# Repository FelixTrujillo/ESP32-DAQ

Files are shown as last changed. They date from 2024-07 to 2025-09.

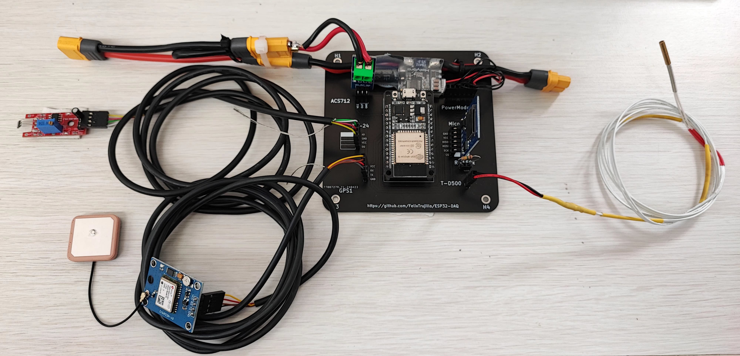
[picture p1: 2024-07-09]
Documentation/Images/DAQ_assembled.jpeg

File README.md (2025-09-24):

# ESP32-DAQ
This repository contains the code and design of a data acquisition device for the battery system of an electric vehicle. Developed with the ESP-WROOM-32, this device records current, voltage, speed and GPS data accurately and efficiently.

Bill of materials: ESP-WROOM-32, Current sensor ACS-712, Power module Holybro PM02, Hall effect sensor KY-024, NEO-6M GPS module, Micro SD storage module, T-D500 Temperature Sensor

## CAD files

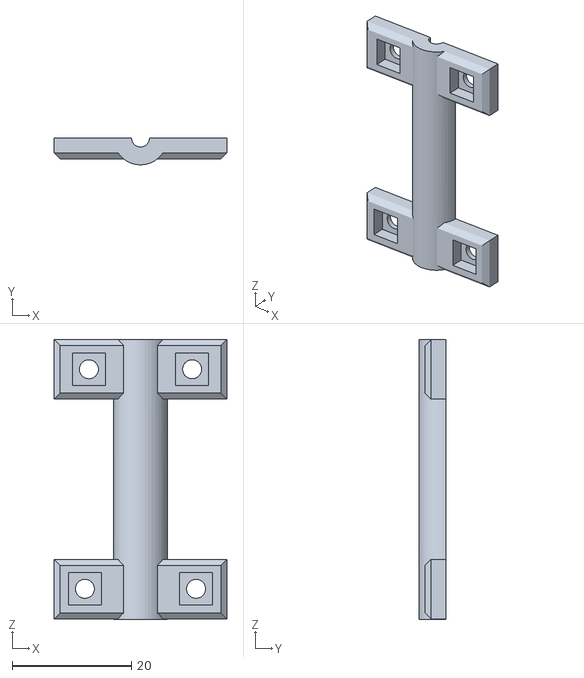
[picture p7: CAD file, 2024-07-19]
DAQ-STEP/BicinetaIman_Soporte_backward_stl.stl
29.0 x 4.50 x 47.0

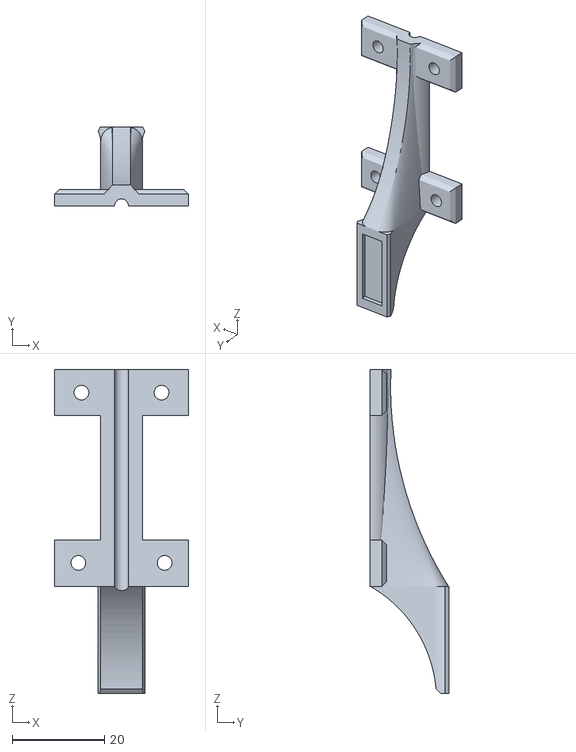
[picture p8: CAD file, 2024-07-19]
DAQ-STEP/Bicineta_Iman_Soporte_Forward_stl.stl
29.0 x 17.0 x 70.1

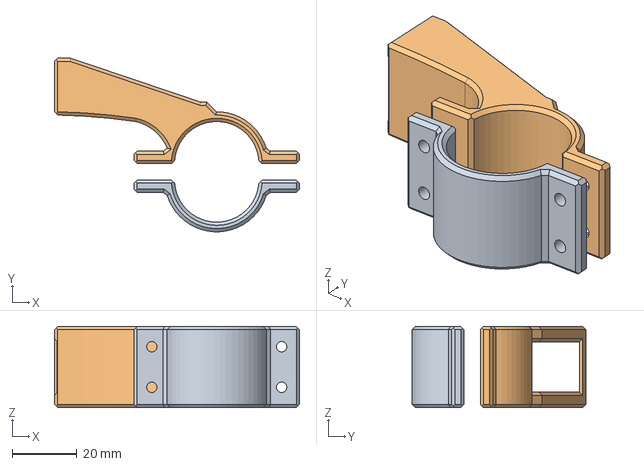
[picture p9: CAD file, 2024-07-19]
DAQ-STEP/Bicineta-stand-ky-024.step
75.5 x 53.5 x 25.0 mm

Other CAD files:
DAQ-STEP/Bicineta_Iman_Soporte_Forward.step
DAQ-STEP/BicinetaIman_Soporte_backward.step

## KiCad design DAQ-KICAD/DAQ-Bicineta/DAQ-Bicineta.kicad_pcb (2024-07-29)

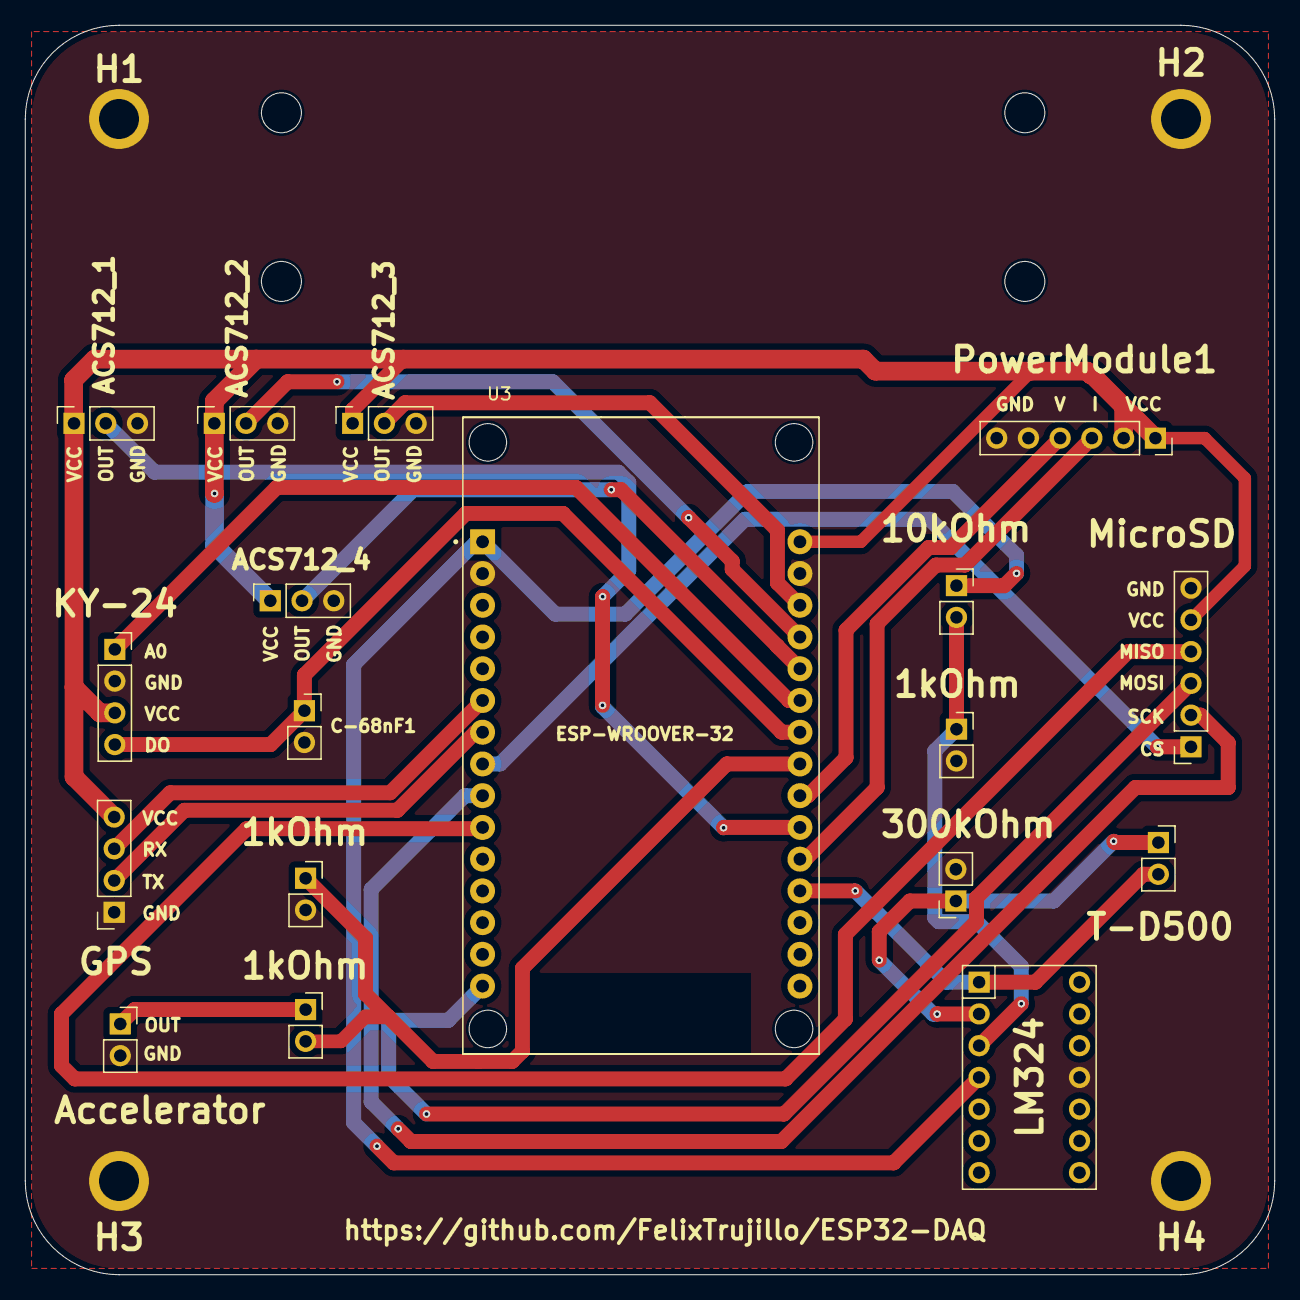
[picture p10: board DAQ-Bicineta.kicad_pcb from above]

Board: 2 copper layers, 100.0 x 100.0 mm, 22 parts (0 on the bottom side), 22 nets.

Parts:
1kOhm, 1kOhm#2, 1kOhm#3, 10kOhm, 300kOhm: R; PinSocket_1x02_P2.54mm_Vertical
ACS712_1, ACS712_2, ACS712_3, ACS712_4: Conn_01x03; PinSocket_1x03_P2.54mm_Vertical
Accelerator: Conn_01x02; PinSocket_1x02_P2.54mm_Vertical
C-68nF1: C_Small; PinSocket_1x02_P2.54mm_Vertical
GPS: Conn_01x04; PinSocket_1x04_P2.54mm_Vertical
H1, H2, H3, H4: MountingHole_2.2mm_M2_ISO7380_Pad
KY-24: Conn_01x04; PinSocket_1x04_P2.54mm_Vertical
LM324: Conn_02x07_Odd_Even; LM324
MicroSD: Conn_01x06; PinSocket_1x06_P2.54mm_Vertical
PowerModule1: Conn_01x06; PinSocket_1x06_P2.54mm_Vertical
T-D500: Conn_01x02; PinSocket_1x02_P2.54mm_Vertical
U3: ESP32-DEVKIT-V1; MODULE_ESP32_DEVKIT_V1

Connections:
ACCELERATOR_GND: 1kOhm#2.2, 1kOhm#3.2, 300kOhm.2, ACS712_1.3, ACS712_2.3, ACS712_3.3, ACS712_4.3, Accelerator.2, C-68nF1.2, GPS.1, H1.1, H2.2, H3.3, H4.4, KY-24.2, LM324.8, MicroSD.6, PowerModule1.5, PowerModule1.6, U3.2 (GND), U3.29 (GND)
ACCELERATOR_Vout: 1kOhm.2, 1kOhm#3.1, U3.23 (D25)
CS_OUT_1: ACS712_1.2, U3.21 (D32)
CS_OUT_2: ACS712_2.2, U3.27 (D12)
CS_OUT_3: ACS712_3.2, U3.28 (D13)
CS_OUT_4: ACS712_4.2, U3.26 (D14)
CS_VCC: ACS712_1.1, ACS712_2.1, ACS712_3.1, ACS712_4.1, GPS.4, KY-24.3, MicroSD.5, PowerModule1.1, PowerModule1.2, U3.30 (VIN)
GPS_RX: GPS.3, U3.6 (RX2)
GPS_TX: GPS.2, U3.7 (TX2)
KY_A0: KY-24.1, U3.25 (D27)
KY_DO: C-68nF1.1, KY-24.4, U3.24 (D26)
MSD_CS: MicroSD.1, U3.8 (D5)
MSD_MISO: MicroSD.4, U3.10 (D19)
MSD_MOSI: MicroSD.3, U3.15 (D23)
MSD_SCK: MicroSD.2, U3.9 (D18)
unnamed: 1kOhm.1, Accelerator.1
unnamed: 300kOhm.1, LM324.3, T-D500.1
unnamed: 1kOhm#2.1, 10kOhm.2, LM324.5
PM_I: PowerModule1.3, U3.20 (D35)
PM_V: PowerModule1.4, U3.22 (D33)
T-D500_OUT: LM324.1, T-D500.2, U3.19 (D34)
T-D500_VCC: 10kOhm.1, LM324.7, U3.1 (3V3)

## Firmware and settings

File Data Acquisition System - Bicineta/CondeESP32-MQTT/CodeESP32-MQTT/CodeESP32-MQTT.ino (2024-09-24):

#include "SD.h"
#include <Arduino.h>
#include <ESP32Servo.h>
#include <TinyGPS++.h>
#include <Wire.h>
#include <HardwareSerial.h>
#include <math.h>

#include <WiFi.h>
#include <PubSubClient.h>
#include <WiFiClientSecure.h>

#define RXD2 16 // Pin RX GPS
#define TXD2 17 // Pin TX GPS
#define GPS_BAUD 9600  // Velocidad de baudios del módulo GPS
#define NMEA 0

// =============================================================

double pinA = 26; // Pin sensor efecto hall
double pinB = 27; // Pin sensor efecto hall analogo (No en uso)

double pinV = 33;  //Pin medir tension PM
double pinI = 32; // Pin medir corriente ACS712
double pin_I = 35; // Pin medir corriente PM (No en uso)
double pinT = 34; // Pin medir temperatura T-D500

int pinCS = 5; // Pin modulo memoria

int pinACC = 39; // Pin Acelerador

// =============================================================


//---- WiFi settings
const char* ssid = "UTP";
const char* password = "tecnologica";
//---- MQTT Broker settings
const char* mqtt_server = "02c9970343eb456bac87e5836a2905c3.s1.eu.hivemq.cloud"; // replace with your broker url
const char* mqtt_username = "GCA_DAQ";
const char* mqtt_password = "#Control2005";
const int mqtt_port =8883;

WiFiClientSecure espClient;
PubSubClient client(espClient);
unsigned long lastMsg = 0;

#define MSG_BUFFER_SIZE (50)
char msg[MSG_BUFFER_SIZE];

const char* sensor1_topic= "voltage";
const char* sensor2_topic= "current";
const char* sensor3_topic= "speed";
const char* sensor4_topic= "acceleration";
const char* sensor5_topic= "temperature";
const char* sensor6_topic= "altitud";


static const char *root_ca PROGMEM = R"EOF(
-----BEGIN CERTIFICATE-----
MIIFazCCA1OgAwIBAgIRAIIQz7DSQONZRGPgu2OCiwAwDQYJKoZIhvcNAQELBQAw
TzELMAkGA1UEBhMCVVMxKTAnBgNVBAoTIEludGVybmV0IFNlY3VyaXR5IFJlc2Vh
cmNoIEdyb3VwMRUwEwYDVQQDEwxJU1JHIFJvb3QgWDEwHhcNMTUwNjA0MTEwNDM4
WhcNMzUwNjA0MTEwNDM4WjBPMQswCQYDVQQGEwJVUzEpMCcGA1UEChMgSW50ZXJu
ZXQgU2VjdXJpdHkgUmVzZWFyY2ggR3JvdXAxFTATBgNVBAMTDElTUkcgUm9vdCBY
MTCCAiIwDQYJKoZIhvcNAQEBBQADggIPADCCAgoCggIBAK3oJHP0FDfzm54rVygc
h77ct984kIxuPOZXoHj3dcKi/vVqbvYATyjb3miGbESTtrFj/RQSa78f0uoxmyF+
0TM8ukj13Xnfs7j/EvEhmkvBioZxaUpmZmyPfjxwv60pIgbz5MDmgK7iS4+3mX6U
A5/TR5d8mUgjU+g4rk8Kb4Mu0UlXjIB0ttov0DiNewNwIRt18jA8+o+u3dpjq+sW
T8KOEUt+zwvo/7V3LvSye0rgTBIlDHCNAymg4VMk7BPZ7hm/ELNKjD+Jo2FR3qyH
B5T0Y3HsLuJvW5iB4YlcNHlsdu87kGJ55tukmi8mxdAQ4Q7e2RCOFvu396j3x+UC
B5iPNgiV5+I3lg02dZ77DnKxHZu8A/lJBdiB3QW0KtZB6awBdpUKD9jf1b0SHzUv
KBds0pjBqAlkd25HN7rOrFleaJ1/ctaJxQZBKT5ZPt0m9STJEadao0xAH0ahmbWn
OlFuhjuefXKnEgV4We0+UXgVCwOPjdAvBbI+e0ocS3MFEvzG6uBQE3xDk3SzynTn
jh8BCNAw1FtxNrQHusEwMFxIt4I7mKZ9YIqioymCzLq9gwQbooMDQaHWBfEbwrbw
qHyGO0aoSCqI3Haadr8faqU9GY/rOPNk3sgrDQoo//fb4hVC1CLQJ13hef4Y53CI
rU7m2Ys6xt0nUW7/vGT1M0NPAgMBAAGjQjBAMA4GA1UdDwEB/wQEAwIBBjAPBgNV
HRMBAf8EBTADAQH/MB0GA1UdDgQWBBR5tFnme7bl5AFzgAiIyBpY9umbbjANBgkq
hkiG9w0BAQsFAAOCAgEAVR9YqbyyqFDQDLHYGmkgJykIrGF1XIpu+ILlaS/V9lZL
ubhzEFnTIZd+50xx+7LSYK05qAvqFyFWhfFQDlnrzuBZ6brJFe+GnY+EgPbk6ZGQ
3BebYhtF8GaV0nxvwuo77x/Py9auJ/GpsMiu/X1+mvoiBOv/2X/qkSsisRcOj/KK
NFtY2PwByVS5uCbMiogziUwthDyC3+6WVwW6LLv3xLfHTjuCvjHIInNzktHCgKQ5
ORAzI4JMPJ+GslWYHb4phowim57iaztXOoJwTdwJx4nLCgdNbOhdjsnvzqvHu7Ur
TkXWStAmzOVyyghqpZXjFaH3pO3JLF+l+/+sKAIuvtd7u+Nxe5AW0wdeRlN8NwdC
jNPElpzVmbUq4JUagEiuTDkHzsxHpFKVK7q4+63SM1N95R1NbdWhscdCb+ZAJzVc
oyi3B43njTOQ5yOf+1CceWxG1bQVs5ZufpsMljq4Ui0/1lvh+wjChP4kqKOJ2qxq
4RgqsahDYVvTH9w7jXbyLeiNdd8XM2w9U/t7y0Ff/9yi0GE44Za4rF2LN9d11TPA
mRGunUHBcnWEvgJBQl9nJEiU0Zsnvgc/ubhPgXRR4Xq37Z0j4r7g1SgEEzwxA57d
emyPxgcYxn/eR44/KJ4EBs+lVDR3veyJm+kXQ99b21/+jh5Xos1AnX5iItreGCc=
-----END CERTIFICATE-----
)EOF";



// Inicializacion variables de corriente, tension, temperatura y aceleracion
double corriente = 0;
double temperatura = 0;
double voltaje = 0;
double accelerator = 0;

// Inicializacion vaiables del GPS
double latGPS;
double longGPS;
double velGPS;
double numSat;
double altGPS;
int hourGPS;
int minGPS;
int yearGPS;

// Parametros sensor de temperatura
double a = -0.015769;
double b = 0.0032072;
double c = -0.00018051;
double d = 3.3808e-06;

// Inicializacion variables sensor de velocidad (HY-024)
volatile int PPSCounter = 0; // Contador de pulsos
unsigned int pulsos = 0;     // Cantidad de pulsos en 1 segundo 
unsigned Time = 0;           // Inicialización variable de tiempo
float RPM = 0;        // Inicializacion variable de velocidad actual
unsigned int RPM_ANT = 0;    // Inicializacion variable de velocidad anterior
int PPR = 2;                // Numero de pulsos que detecta el sensor por vuelta
double debounceDelay = 120;
double debounceTime = 0;
double lastDebounceTime = 0;

// Parametros sensor de corriente ACS712
double mVperAmp = 0.1;       // Sensibilidad sensor de corriente ACS712

// Numero de muestras para la medicion de datos
int muestras = 1000;

TinyGPSPlus gps;
HardwareSerial gpsSerial(2);

File archivo;
String datos;

void IRAM_ATTR magnetDetection();
int getRPM();
double getCurrent(int numMuestras);
double getVoltage(int numMuestras1);
double getTemp(int numMuestras1);
double getSignalAcceleration(int numMuestras1);

void setup() {

  Serial.begin(115200);

  pinMode(pinCS, OUTPUT);
  pinMode(pinV, INPUT);
  pinMode(pinI, INPUT);
  pinMode(pinACC, INPUT);
  pinMode(pinA, INPUT_PULLUP);

  Serial.print("\nConnecting to ");
  Serial.println(ssid);
  WiFi.mode(WIFI_STA);
  WiFi.begin(ssid, password);
  while (WiFi.status() != WL_CONNECTED) {
  delay(500);
  Serial.print(".");
  }
  randomSeed(micros());
  Serial.println("\nWiFi connected\nIP address: ");
  Serial.println(WiFi.localIP());

  while (!Serial) delay(1);

  espClient.setCACert(root_ca);
  client.setServer(mqtt_server, mqtt_port);
  client.setCallback(callback);

  gpsSerial.begin(GPS_BAUD, SERIAL_8N1, RXD2, TXD2);

  attachInterrupt(digitalPinToInterrupt(pinA), magnetDetection, HIGH);

  Time = millis();

  

  if (!SD.begin(pinCS)) {
    Serial.println("ERROR:\n Puerto CS no inicializado.");
    ESP.restart();
  }
  Serial.println("Modulo CS inicializado.");

  archivo = SD.open("/registro.CSV", FILE_WRITE);
  if (!archivo) {
    Serial.println("ERROR:\n No se ha podido crear el archivo.");
    return;
  }

  archivo.println("Velocidad [RPM],Aceleracion [V_Acc], Voltaje[V],Corriente[A],Temperatura[°C],Latitud,Longitud,Velocidad[GPS: km/h],Satelites, Altitud, Hora, Minutos, Year");
  archivo.close();
}

void loop() {

    if (!client.connected()) reconnect();
  client.loop();


  // Apertura del archivo "Registro"
  archivo = SD.open("/registro.CSV", FILE_APPEND);

  // Lectura de velocidad con el encoder
  RPM = getRPM();
  accelerator = getSignalAcceleration(muestras); 
  // Lectura de temperatura
  temperatura = getTemp(muestras);

  // lectura de datos de tension y corriente
  voltaje = getVoltage(muestras);

  if (voltaje == 0 || corriente < 0) {
    corriente = 0;
  }
  else {
    corriente = getCurrent(muestras);
  }



  while (gpsSerial.available() > 0) {
    if (gps.encode(gpsSerial.read())) {
      if (gps.location.isUpdated()) {
        // Si se ha recibido una nueva actualización de ubicación, muestra la información
        latGPS = gps.location.lat();
        longGPS = gps.location.lng();
        velGPS = gps.speed.kmph();
        numSat = gps.satellites.value();
        altGPS = gps.altitude.meters();
        hourGPS = gps.time.hour();
        minGPS = gps.time.minute();
        yearGPS = gps.date.year();

        
      };
    };
  };
  // Creacion String datos para la generacion del formato .CSV
  if (archivo) {
          datos = String(String(RPM) +","+ String(accelerator) + "," + String(voltaje, 8) + "," + String(corriente, 8) + "," + String(temperatura, 8) +
                         "," + String(latGPS, 15) + "," + String(longGPS, 15) + "," + String(velGPS, 8) + "," + String(numSat) + "," + String(altGPS, 8) + "," + String(hourGPS) + "," + String(minGPS) +
                         "," + String(yearGPS));


          //Almacenar SD en formato .CSV
          archivo.println(datos);
          archivo.close();
        };

        // Serial.print("Velocidad [RPM]: ");
        // Serial.print(RPM);
        // Serial.print(",");
        // Serial.print("Aceleracion [V_Acc]: ");
        // Serial.print(accelerator);
        // Serial.print(",");
        // Serial.print("Voltaje [V]: ");
        // Serial.print(voltaje);
        // Serial.print(",");
        // Serial.print("Corriente [A]: ");
        // Serial.print(corriente);
        // Serial.print(",");
        // Serial.print("Temperatura [°C]: ");
        // Serial.print(temperatura);
        // Serial.print(",");
        // // Lectura de datos GPS
        // Serial.print("Latitud: ");
        // Serial.print(latGPS);
        // Serial.print(",");
        // Serial.print("Longitud: ");
        // Serial.print(longGPS);
        // Serial.print(",");
        // Serial.print("Velocidad [km/h]: ");
        // Serial.print(velGPS);
        // Serial.print(",");
        // Serial.print("Satelites: ");
        // Serial.print(numSat);
        // Serial.print(",");
        // Serial.print("Altitud: ");
        // Serial.print(altGPS);
        // Serial.print(",");
        // Serial.print("Hora: ");
        // Serial.print(hourGPS);
        // Serial.print(",");
        // Serial.print("Minutos: ");
        // Serial.print(minGPS);
        // Serial.print(",");
        // Serial.print("Año: ");
        // Serial.println(yearGPS);
        
        publishMessage(sensor1_topic,String(voltaje),true);    
        publishMessage(sensor2_topic,String(corriente),true);
        publishMessage(sensor3_topic,String(RPM),true);
        publishMessage(sensor4_topic,String(accelerator),true);
        publishMessage(sensor5_topic,String(temperatura),true);
        publishMessage(sensor6_topic,String(altGPS),true);

        delay(1000);
      
}

void reconnect() {
  // Loop until we’re reconnected
  while (!client.connected()) {
  Serial.print("Attempting MQTT connection…");
  String clientId = "ESP8266Client-"; // Create a random client ID
  clientId += String(random(0xffff), HEX);
  // Attempt to connect
  if (client.connect(clientId.c_str(), mqtt_username, mqtt_password)) {
    Serial.println("connected");

    client.subscribe(sensor1_topic);   // subscribe the topics here
    client.subscribe(sensor2_topic);   // subscribe the topics here
    client.subscribe(sensor3_topic);   // subscribe the topics here
    client.subscribe(sensor4_topic);   // subscribe the topics here
    client.subscribe(sensor5_topic);   // subscribe the topics here
    client.subscribe(sensor6_topic);   // subscribe the topics here
    
  } else {
    Serial.print("failed, rc=");
    Serial.print(client.state());
    Serial.println(" try again in 5 seconds");   // Wait 5 seconds before retrying
    delay(5000);
  }
  }
}

//=======================================
// This void is called every time we have a message from the broker

void callback(char* topic, byte* payload, unsigned int length) {
  String incommingMessage = "";
  for (int i = 0; i < length; i++) incommingMessage+=(char)payload[i];
  Serial.println("Message arrived ["+String(topic)+"]"+incommingMessage);
  // check for other commands
  /* else if( strcmp(topic,command2_topic) == 0){
  if (incommingMessage.equals(“1”)) { } // do something else
  }
  */
}

//======================================= publising as string
void publishMessage(const char* topic, String payload , boolean retained){
  if (client.publish(topic, payload.c_str(), true))
  Serial.println("Message published ["+String(topic)+"]: "+payload);
}

void IRAM_ATTR magnetDetection(){

    debounceTime = millis();

    if((debounceTime - lastDebounceTime) > debounceDelay){

      PPSCounter++;
      lastDebounceTime = debounceTime;

    }
    
    
}

int getRPM(){
  
  if (millis() - Time >= 1000) {

      pulsos = PPSCounter;
      RPM_ANT = RPM;
      RPM = (60 * pulsos / (PPR));
      PPSCounter = 0;
      pulsos = 0;
      Time = millis();

  }

  if(RPM <= 450){
    debounceDelay = 93;
  }
  else if(RPM > 450 && RPM <= 750){
      debounceDelay = 53;
  }
  else if(RPM > 750 && RPM <= 1000){
    debounceDelay = 33;
  }
  else if(RPM > 1000){
    debounceDelay = 5;
  }
  //Serial.println(debounceDelay);
  return RPM;

}

double getCurrent(int numMuestras){

  double vSensor = 0;
  double iSensor = 0;
  double error = 0;
  for (int i = 0; i < numMuestras; i++) {
    vSensor = analogRead(pinI) * (5.5 / 4096.0);
    iSensor += (vSensor-2.5)/mVperAmp;
  }
  
  iSensor = (iSensor/numMuestras);
  error = 0.6231*iSensor+6.1885;
  iSensor = iSensor - error;
  
  return iSensor;
}

double getVoltage(int numMuestras1){

  double vSensor1 = 0;
  double volt = 0;
  double error = 0;
  for (int j = 0; j < numMuestras1; j++) {
    vSensor1 = analogRead(pinV) * 2 / 100.0;
    volt += vSensor1;
  }
  volt = (volt / numMuestras1);
  error = 0.29729*volt-2.301628;
  volt = volt - error;
 
  if (volt < 0 || analogRead(pinV) == 0) {
    volt = 0;
  }
  return volt;
}

double getTemp(int numMuestras1){
  //double RT = 0;
  //double R2 = 150e3;
  //double Vin = 3.3;
  double Vout = 0;
  double V = 0;
  double T = 0;
  int numMuestras2 = numMuestras1 + 5000;
  for (int k = 0; k < numMuestras2; k++) {
    Vout = analogRead(pinT) * 3.3 / 4095;
    V += Vout;
  }

  V = V / numMuestras2;
  //RT = R2 / ((Vin / V) - 1);
  //T = (1 / (a + b * log(RT) + c * pow(log(RT), 2) + d * pow(log(RT), 3))) - 273.15;
  T = 153*exp(-0.87*V);
  return T;
}

double getSignalAcceleration(int numMuestras1){
  double SignalAcc = 0 ;
  double VAcc = 0;
  for(int i = 0; i < numMuestras1; i++ ){
    VAcc = analogRead(pinACC)*3.3/4095;
    SignalAcc += VAcc;
  }
  Serial.println(VAcc);
  SignalAcc = SignalAcc / numMuestras1;
  return SignalAcc;
}

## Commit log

2024-04-16 Upload Project Files
    In this commit the addition of the different parts of the project is carried out, both the addition of the code and the PCB design.
    [DAQ-Bicineta-B_Cu.gbr, DAQ-Bicineta-B_Mask.gbr, DAQ-Bicineta-B_Paste.gbr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]
2024-04-22 DAQ_STEP
    The PCB modifications are made to incorporate the T-D500 and the CAD design of the DAQ card is carried out.
    [DAQ-Bicineta.kicad_pcb]
2024-04-22 Name update
    The modification of the folder names is carried out
    [DAQ-Bicineta-B_Cu.gbr, DAQ-Bicineta-B_Mask.gbr, DAQ-Bicineta-B_Paste.gbr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]
2024-06-06 PCB-Validation
    The necessary tests and modifications for the final operation on the printed circuit board are carried out; the validation of the GPS functionality is still pending.
2024-06-21 Sensor-Calibration
    Calibration of the current, temperature sensors
2024-06-24 Update of Temperature Sensor and Hall Effect Parameters
    The temperature sensor was calibrated to update the parameters of the equation, and the Hall effect sensor was optimally coupled.
2024-06-24 Introduction to the Uplox 6m GPS Sensor
    The Ublo-6m sensor is configured and implemented on the data acquisition board. Additionally, the code is reviewed to clean and organize it, removing the current1 value from the power module's curren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
2024-07-19 T-D500 and KY-024 calibration
    [Bicineta-stand-ky-024.step, BicinetaIman_Soporte_backward.step, BicinetaIman_Soporte_backward_stl.stl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]
2024-09-24 Matlab Identification - Folder
    [TakeDataBicinetaPath-1-2-3.xlsx, TakeDataBicinetaPath4.xlsx, pyvenv.cfg]
